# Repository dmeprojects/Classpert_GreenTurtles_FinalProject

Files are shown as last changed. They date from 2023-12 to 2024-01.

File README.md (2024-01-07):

# Classpert_GreenTurtles final project: Aim-A-Lyzer

## Links & external files
[Project report](https://docs.google.com/document/d/1ELGmE2rww3Yx6WdUTNhLceJI5xqiP-OGn81cCfm_2fU/edit#heading=h.1g53q35e8x0j)

[Device states](https://docs.google.com/spreadsheets/d/1XaL28H3fuIrutpEAfPE2s_Nis7TtN3zFUXbInfYVTSA/edit#gid=0)

[Youtube video](https://www.youtube.com/watch?v=wXm_mhuhDJE)

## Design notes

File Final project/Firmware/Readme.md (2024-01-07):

# Classpert final project: Aim-A-Lyzer

#Project report:
https://docs.google.com/document/d/1OVRfLsmoFKODwGaWP3o3U3_KX_a43jo9WVvBxGMvw9w/edit?usp=sharing

## Goal

## Hardware

### Hardware block diagram

### Software

##Libraries used;

MPU6050:
https://github.com/leech001/MPU6050

DMA info:
https://www.st.com/resource/en/application_note/an4031-using-the-stm32f2-stm32f4-and-stm32f7-series-dma-controller-stmicroelectronics.pdf

STM32 HAL user manual:
https://www.st.com/resource/en/user_manual/um1725-description-of-stm32f4-hal-and-lowlayer-drivers-stmicroelectronics.pdf

Embedded Artistery hard fault debugging:

https://embeddedartistry.com/blog/2021/01/11/hard-fault-debugging/

Asserts:

https://interrupt.memfault.com/blog/asserts-in-embedded-systems

STM viewer:

https://interrupt.memfault.com/blog/stm-viewer-debug

Unit testing:

https://interrupt.memfault.com/blog/unit-testing-basics

FatFS:
http://elm-chan.org/fsw/ff/

SD card info:
https://chlazza.nfshost.com/sdcardinfo.html

FAT FS: demo:
https://www.youtube.com/watch?v=I9KDN1o6924

SD card in SPI mode:
https://blog.domski.pl/using-fatfs-with-hal/
https://github.com/eziya/STM32_SPI_SDCARD/tree/master

STM32 SD card with SDIO:
https://www.youtube.com/watch?v=spVIZO-jbxE

#Asci art:
https://patorjk.com/software/taag/#p=testall&f=Big%20Money-sw&t=Aim-A-Lyzer

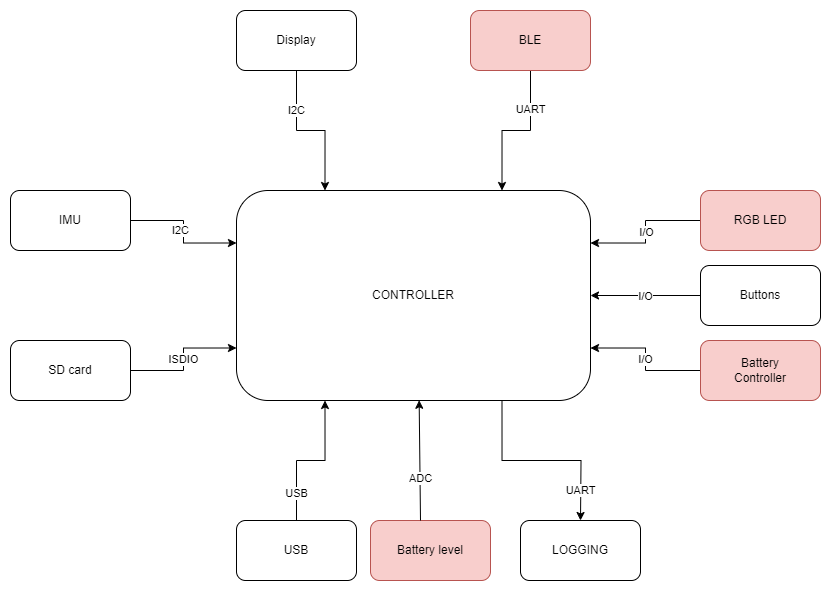
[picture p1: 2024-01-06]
docs/Hardware block diagram.png

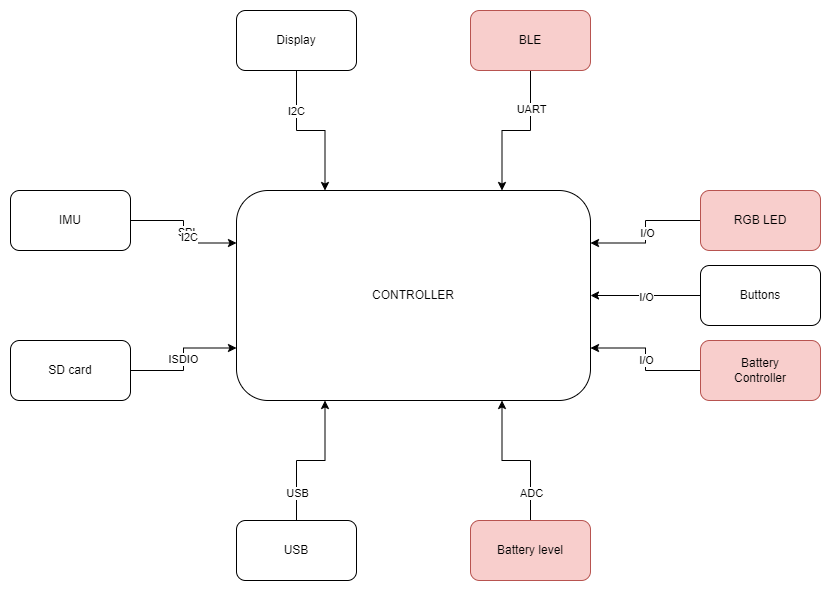
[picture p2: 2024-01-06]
docs/Hardware block diagram_MVP.png

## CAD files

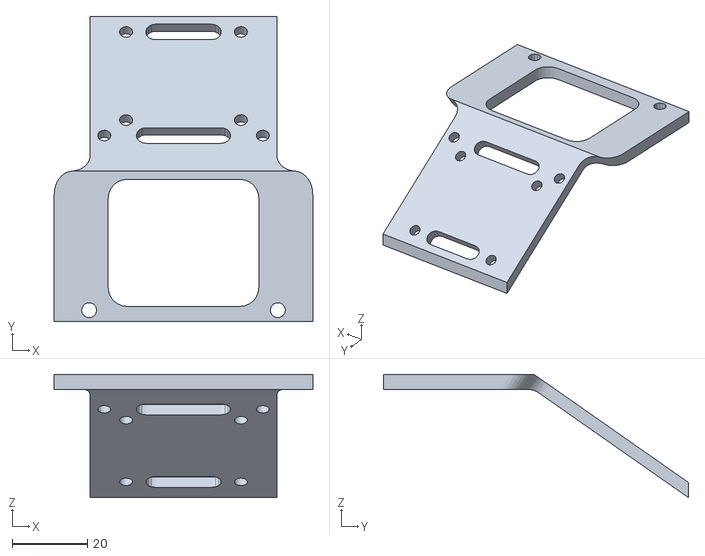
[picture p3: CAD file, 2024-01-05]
Mechanical/casing/3dPrintFiles/UserInterface mount.stl
68.5 x 80.8 x 32.7

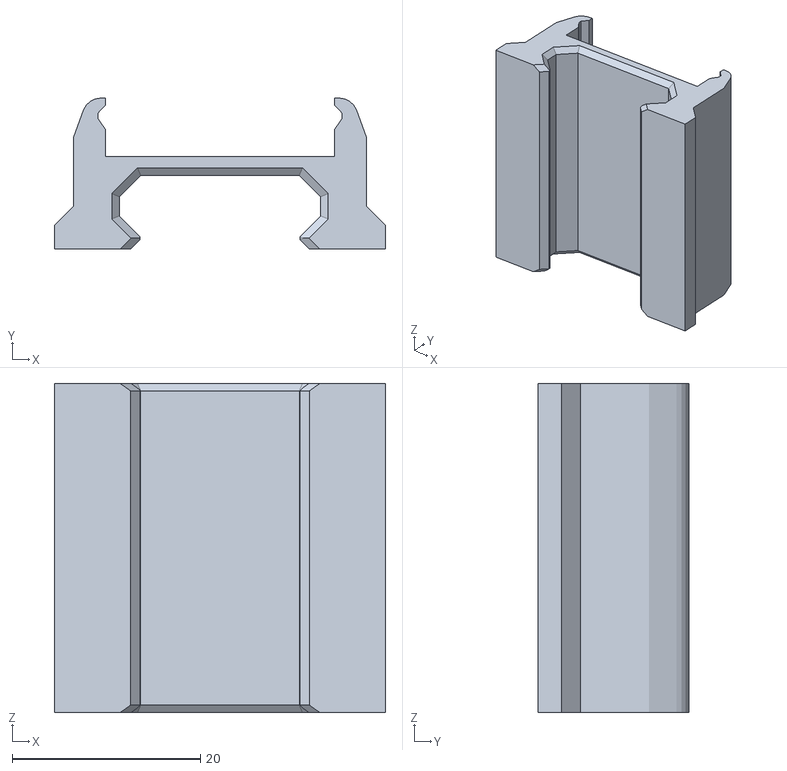
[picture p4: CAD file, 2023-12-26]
Mechanical/Rail clamp.stl
35.2 x 16.1 x 35.0

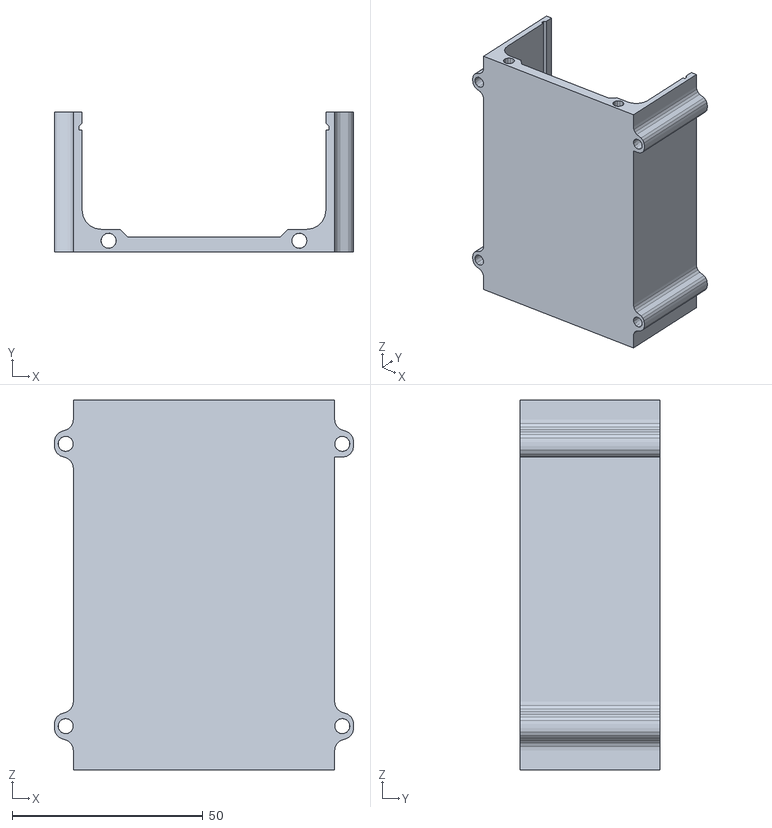
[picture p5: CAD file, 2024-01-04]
Mechanical/casing/3dPrintFiles/Discovery boar holder.stl
78.5 x 36.8 x 97.0

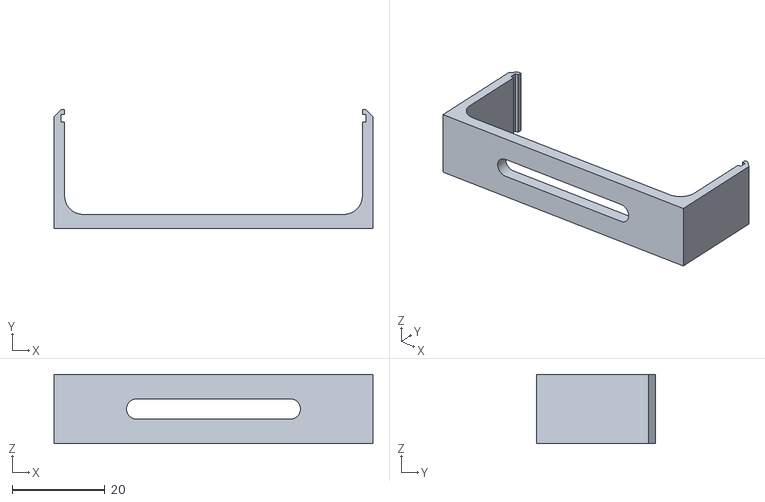
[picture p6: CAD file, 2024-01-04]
Mechanical/casing/3dPrintFiles/Discovery boar clamp.stl
68.9 x 25.6 x 15.0

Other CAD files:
Mechanical/IMU Module.ipt
Mechanical/OldVersions/IMU Module.0001.ipt
Mechanical/OldVersions/Rail assembly.0004.iam
Mechanical/OldVersions/Rail clamp.0008.ipt
Mechanical/Rail assembly.iam
Mechanical/Rail clamp.ipt
Mechanical/Rail/Picatinny model.ipt
Mechanical/casing/3dPrintFiles/OldVersions/aim-a-lyzer assy.0002.iam
Mechanical/casing/3dPrintFiles/aim-a-lyzer assy.iam
Mechanical/casing/Discovery boar clamp.ipt
Mechanical/casing/Discovery boar holder.ipt
Mechanical/casing/Discovery board.ipt
Mechanical/casing/OldVersions/Discovery boar clamp.0002.ipt
Mechanical/casing/OldVersions/Discovery boar holder.0001.ipt
Mechanical/casing/SD card holder.ipt
Mechanical/casing/UserInterface mount.ipt

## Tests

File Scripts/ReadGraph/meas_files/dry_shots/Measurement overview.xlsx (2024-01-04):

Measurement # | descirption
5 | 3x dry shots

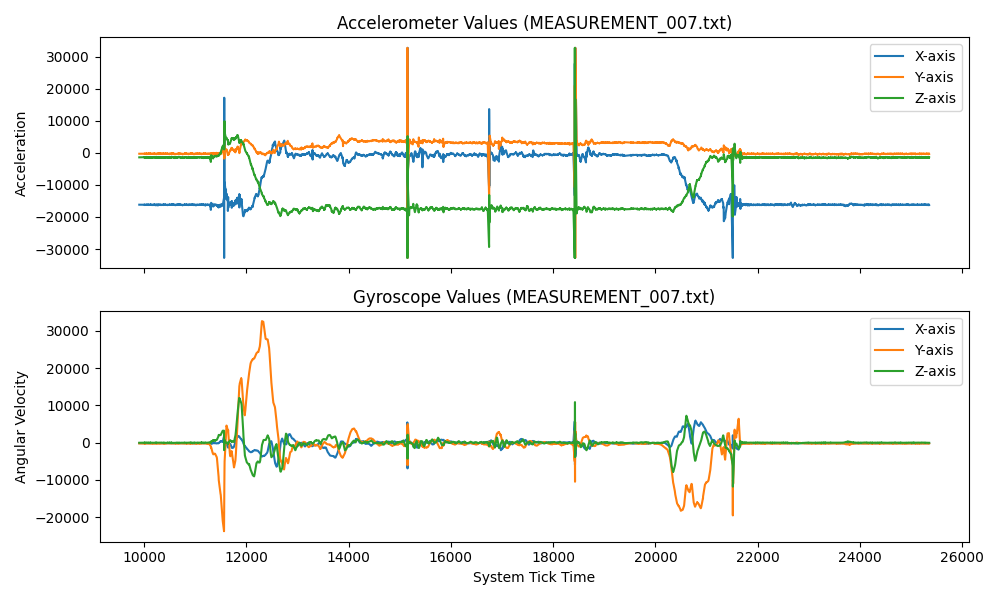
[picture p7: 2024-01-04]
Scripts/ReadGraph/meas_files/dry_shots/MEASUREMENT_007.txt.png

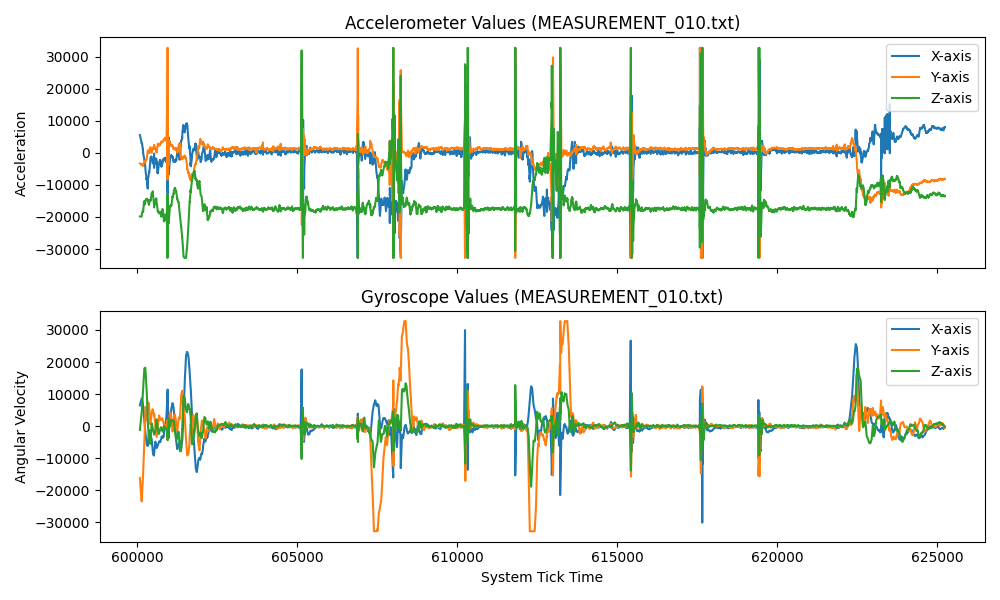
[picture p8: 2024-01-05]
Scripts/ReadGraph/meas_files/live rounds/MEASUREMENT_010.png

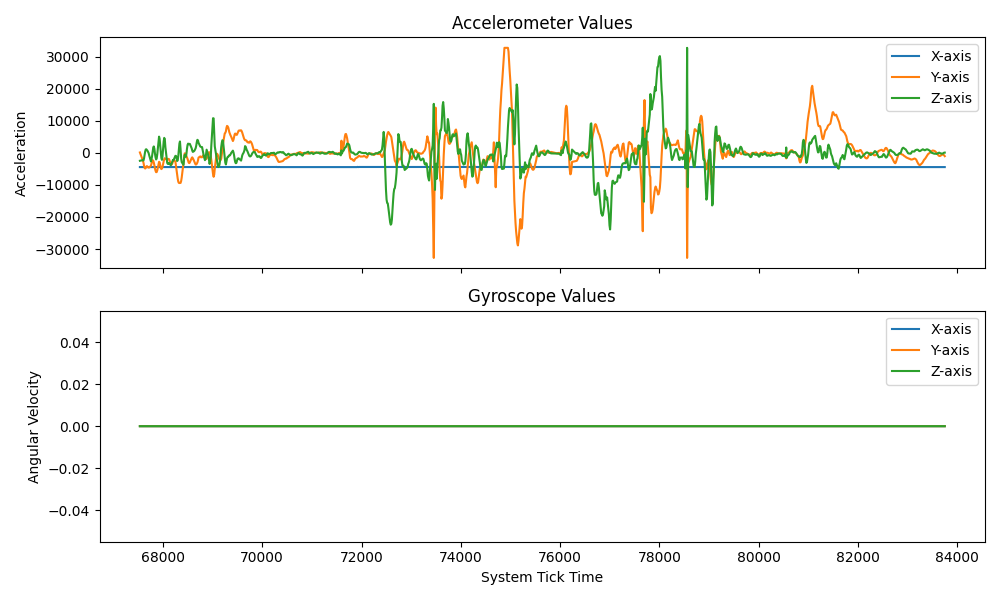
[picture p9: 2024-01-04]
Scripts/ReadGraph/meas_files/MEASUREMENT_005.png

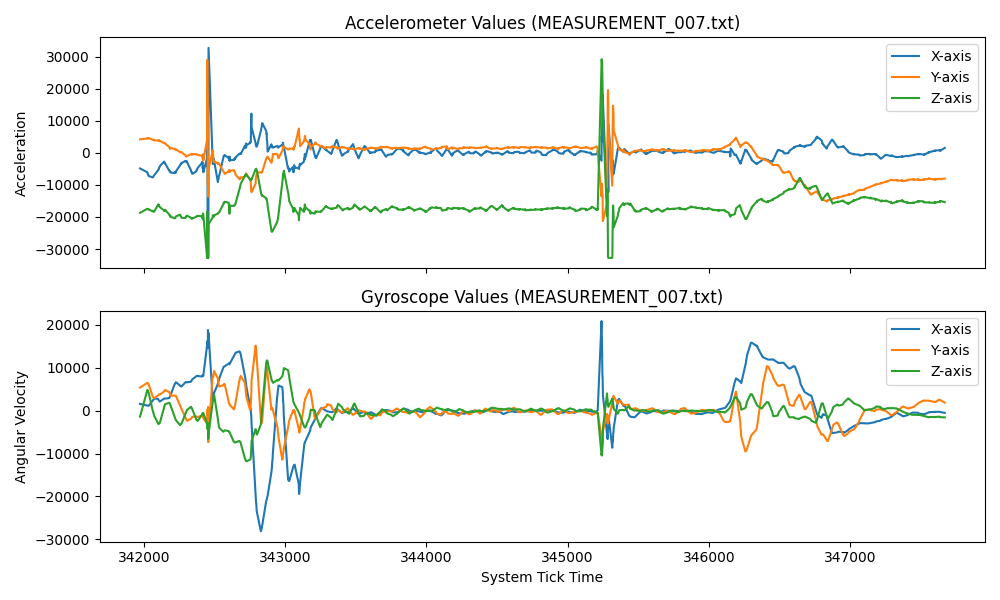
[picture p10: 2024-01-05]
Scripts/ReadGraph/meas_files/live rounds/MEASUREMENT_007.png

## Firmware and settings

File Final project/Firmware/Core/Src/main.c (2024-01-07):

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
/* Includes ------------------------------------------------------------------*/
#include "main.h"
#include "fatfs.h"
#include "usb_device.h"

/* USER CODE BEGIN Includes */
#include "custom_pindefines.h"
#include "state_defines.h"
#include "version.h"
#include "app.h"
#include "console.h"
#include "displayFunctions.h"
#include "mpu6050.h"
#include "usbd_cdc_if.h"
#include "string.h"
#include "stdarg.h"
#include "terminalColorCodes.h"
#include "logging.h"
#include "sd_handler.h"

#include "printHeader.h"
/* USER CODE END Includes */

/* USER CODE BEGIN PD */
#define ERROR_LED_DELAY	1000000
#define	ERROR_PRINT_DELAY	50
#define PUTCHAR_PROTOTYPE int __io_putchar(int ch)


#define LIBRARY_LOG_LEVEL	LOG_INFO

#define	LIBRARY_LOG_NAME	"MAIN"

/*Define if the logging output has to be send trough UART or USB.  The USB doubles as the commandline connection.
 *
 * */
#define LOGUART
//#define LOGUSB

/* USER CODE END PD */

I2C_HandleTypeDef hi2c1;
I2C_HandleTypeDef hi2c3;
DMA_HandleTypeDef hdma_i2c3_rx;

RNG_HandleTypeDef hrng;

RTC_HandleTypeDef hrtc;

SD_HandleTypeDef hsd;
DMA_HandleTypeDef hdma_sdio_rx;
DMA_HandleTypeDef hdma_sdio_tx;

SPI_HandleTypeDef hspi1;

TIM_HandleTypeDef htim2;

UART_HandleTypeDef huart2;

/* USER CODE BEGIN PV */
deviceStates_t deviceStates;
MPU6050_t mpu6050;

const char xCompileDate[] = __DATE__;
const char xCompileTime[] = __TIME__;

/* USER CODE END PV */

void SystemClock_Config(void);
static void MX_GPIO_Init(void);
static void MX_DMA_Init(void);
static void MX_I2C1_Init(void);
static void MX_TIM2_Init(void);
static void MX_RNG_Init(void);
static void MX_USART2_UART_Init(void);
static void MX_I2C3_Init(void);
static void MX_SPI1_Init(void);
static void MX_SDIO_SD_Init(void);
static void MX_RTC_Init(void);
/* USER CODE BEGIN PFP */
uint8_t sdCardpresentVar = 0;
uint32_t buttonPressed = 0;


/* USER CODE END PFP */

/**
  * @brief  The application entry point.
  * @retval int
  */
int main(void)
{
  /* USER CODE BEGIN 1 */
	unsigned char usbString[200];
  /* USER CODE END 1 */

  /* MCU Configuration--------------------------------------------------------*/

  /* Reset of all peripherals, Initializes the Flash interface and the Systick. */
  HAL_Init();

  /* Configure the system clock */
  SystemClock_Config();

  /* Initialize all configured peripherals */
  MX_GPIO_Init();
  MX_DMA_Init();
  MX_I2C1_Init();
  MX_TIM2_Init();
  MX_USB_DEVICE_Init();
  MX_RNG_Init();
  MX_USART2_UART_Init();
  MX_I2C3_Init();
  MX_FATFS_Init();
  MX_SPI1_Init();
  MX_SDIO_SD_Init();
  MX_RTC_Init();
  /* USER CODE BEGIN 2 */

  HAL_Delay(3000);	//Delay allows to reconnect USB after reboot

  printHeader();

  HAL_Delay(500);

  /*Print Firmware version*/
  logInfo( "Classpert Green Turtels Final project");
  logInfo("Aim-A-Lyzer, version: %d.%d.%d", FIRMWARE_MAJOR, FIRMWARE_MINOR, FIRMWARE_BUILD);
  logInfo("Build on: %s at %s", __DATE__, __TIME__);
  logInfo( "Created by Nick Meynen");

  startConsole();

  /* USER CODE END 2 */

  /* Infinite loop */
  /* USER CODE BEGIN WHILE */
  while (1)
  {
	  mainApp();
    /* USER CODE END WHILE */

    /* USER CODE BEGIN 3 */
  }
  /* USER CODE END 3 */
}

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
/* USER CODE BEGIN 4 */
void HAL_GPIO_EXTI_Callback(uint16_t GPIO_Pin)
{
	//HAL_GPIO_TogglePin(GPIOD, LED_ORANGE);
	//Start timer
	if(GPIO_Pin == BTN_OK || GPIO_Pin == BTN_DWN || GPIO_Pin == BTN_UP)
	{
		HAL_TIM_Base_Start_IT(&htim2);
	}
}

void HAL_TIM_PeriodElapsedCallback(TIM_HandleTypeDef *htim)
{

	if(htim->Instance == TIM2)	//Button debounce timer
	{
		htim2.Instance->SR &= ~TIM_SR_UIF;	//Clear int pending flag
		htim2.Instance->SR &= ~TIM_SR_TIF;	//Clear trigger interrupt flag
		htim2.Init.Period = 0;

		if(HAL_GPIO_ReadPin(GPIOE, BTN_OK) == 0)
		{
			HAL_GPIO_TogglePin(GPIOD, LED_ORANGE);
			buttonPressed = BTN_OK;
		}

		if(HAL_GPIO_ReadPin(GPIOE, BTN_UP) == 0)
		{
			HAL_GPIO_TogglePin(GPIOD, LED_GREEN);
			buttonPressed = BTN_UP;
		}

		if(HAL_GPIO_ReadPin(GPIOE, BTN_DWN) == 0)
		{
			HAL_GPIO_TogglePin(GPIOD, LED_BLUE);
			buttonPressed = BTN_DWN;
		}

		HAL_TIM_Base_Stop(&htim2);
		__HAL_TIM_SET_COUNTER(&htim2, 20000);
	}

}

void HAL_DMA_Callback(DMA_HandleTypeDef * hdma)
{
	//Toggle orange LED
	HAL_GPIO_TogglePin(GPIOD, LED_ORANGE);

}

void HAL_I2C_MasterRxCptlCallback(I2C_HandleTypeDef * hi2c)
{
	HAL_GPIO_TogglePin(GPIOD, LED_GREEN);
}

void HAL_I2C_MemRxCpltCallback(I2C_HandleTypeDef *hi2c)
{
	HAL_GPIO_TogglePin(GPIOD, LED_BLUE);
}

PUTCHAR_PROTOTYPE
{
#ifdef LOGUART
	HAL_UART_Transmit(&huart2, (uint8_t *)&ch, 1, 0xFFFF);
	return 0;
#endif

#ifdef LOGUSB
	CDC_Transmit_FS((uint8_t *)&ch, 1);
	return 0;
#endif
}

/* USER CODE END 4 */
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


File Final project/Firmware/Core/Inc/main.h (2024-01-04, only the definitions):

#define CS_I2C_SPI_Pin GPIO_PIN_3
#define CS_I2C_SPI_GPIO_Port GPIOE
#define PC14_OSC32_IN_Pin GPIO_PIN_14
#define PC14_OSC32_IN_GPIO_Port GPIOC
#define PC15_OSC32_OUT_Pin GPIO_PIN_15
#define PC15_OSC32_OUT_GPIO_Port GPIOC
#define PH0_OSC_IN_Pin GPIO_PIN_0
#define PH0_OSC_IN_GPIO_Port GPIOH
#define PH1_OSC_OUT_Pin GPIO_PIN_1
#define PH1_OSC_OUT_GPIO_Port GPIOH
#define OTG_FS_PowerSwitchOn_Pin GPIO_PIN_0
#define OTG_FS_PowerSwitchOn_GPIO_Port GPIOC
#define B1_Pin GPIO_PIN_0
#define B1_GPIO_Port GPIOA
#define B1_EXTI_IRQn EXTI0_IRQn
#define BOOT1_Pin GPIO_PIN_2
#define BOOT1_GPIO_Port GPIOB
#define BTN_UP_Pin GPIO_PIN_11
#define BTN_UP_GPIO_Port GPIOE
#define BTN_UP_EXTI_IRQn EXTI15_10_IRQn
#define BTN_OK_Pin GPIO_PIN_13
#define BTN_OK_GPIO_Port GPIOE
#define BTN_OK_EXTI_IRQn EXTI15_10_IRQn
#define BTN_DWN_Pin GPIO_PIN_15
#define BTN_DWN_GPIO_Port GPIOE
#define BTN_DWN_EXTI_IRQn EXTI15_10_IRQn
#define LD4_Pin GPIO_PIN_12
#define LD4_GPIO_Port GPIOD
#define LD3_Pin GPIO_PIN_13
#define LD3_GPIO_Port GPIOD
#define LD5_Pin GPIO_PIN_14
#define LD5_GPIO_Port GPIOD
#define LD6_Pin GPIO_PIN_15
#define LD6_GPIO_Port GPIOD
#define IMU_INT_Pin GPIO_PIN_6
#define IMU_INT_GPIO_Port GPIOC
#define SD_DET_Pin GPIO_PIN_7
#define SD_DET_GPIO_Port GPIOC
#define VBUS_FS_Pin GPIO_PIN_9
#define VBUS_FS_GPIO_Port GPIOA
#define OTG_FS_DM_Pin GPIO_PIN_11
#define OTG_FS_DM_GPIO_Port GPIOA
#define OTG_FS_DP_Pin GPIO_PIN_12
#define OTG_FS_DP_GPIO_Port GPIOA
#define SWDIO_Pin GPIO_PIN_13
#define SWDIO_GPIO_Port GPIOA
#define SWCLK_Pin GPIO_PIN_14
#define SWCLK_GPIO_Port GPIOA
#define Audio_RST_Pin GPIO_PIN_4
#define Audio_RST_GPIO_Port GPIOD
#define OTG_FS_OverCurrent_Pin GPIO_PIN_5
#define OTG_FS_OverCurrent_GPIO_Port GPIOD
#define Audio_SCL_Pin GPIO_PIN_6
#define Audio_SCL_GPIO_Port GPIOB
#define Audio_SDA_Pin GPIO_PIN_9
#define Audio_SDA_GPIO_Port GPIOB
#define MEMS_INT2_Pin GPIO_PIN_1
#define MEMS_INT2_GPIO_Port GPIOE

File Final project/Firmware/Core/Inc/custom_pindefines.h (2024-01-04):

/*
 * custom_pindefines.h
 *
 *  Created on: Oct 15, 2023
 *      Author: nick_
 */

#ifndef INC_CUSTOM_PINDEFINES_H_
#define INC_CUSTOM_PINDEFINES_H_

#define LED_GREEN	LD4_Pin
#define	LED_RED		LD5_Pin
#define	LED_ORANGE	LD3_Pin
#define	LED_BLUE	LD6_Pin

#define BUTTON1		B1_Pin
#define BTN_UP		BTN_UP_Pin
#define	BTN_DWN		BTN_DWN_Pin
#define BTN_OK		BTN_OK_Pin



#endif /* INC_CUSTOM_PINDEFINES_H_ */

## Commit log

2023-10-12 created cube MX project for STM eval board
2023-10-12 Added timer2 as general purpose timer
2023-10-15 Remnoved old project due to toolchain config issues and created a new one.
    [main.c, main.h]
2023-10-15 Added blinking LEDS with 100ms delay between
2023-10-20 Started mechanical drafting + added interrupts to week 3 assignment
    [IMU Module.ipt, Picatinny model.ipt, Rail assembly.iam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]
2023-10-26 Added CAD files
    [Rail assembly.0001.iam, Rail assembly.iam, Rail clamp.0002.ipt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]
2023-10-26 Fixed code and working CDC
    [app.c]
2023-10-30 Removed driver, middleware, and usb host from gitignore file
2023-11-01 Code runs with USB active, but still crashes when receiving a character
    [app.c, consoleIO.c, main.c]
2023-11-05 fixed console for USB CDC
    [app.c, consoleIO.c]
2023-11-05 Added LED pattern to commands
2023-11-05 Added imu registers
2023-11-06 SPI implemented, but has still the wrong data on the logic analyzer
    [main.c]
2023-11-08 Fixed SPI communication. Added reset of the IMU before the read out of who am i reg
2023-11-08 Fixed spi issue. Installed accellerometer is the LIS3DSH. Inserted the STM32 libraries
    [main.c]
2023-11-16 Added diagrams to the final project folder and adjusted the IMU PCB heigth in the mechanical design
    [Rail assembly.0001.iam, Rail assembly.0002.iam, Rail assembly.iam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]
2023-11-16 Added SSD1306 for STM32 submodule
2023-11-16 Increased the heigth of the IMU on the rail clamp
    [Rail clamp.0004.ipt, Rail clamp.0005.ipt, Rail clamp.ipt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]
2023-11-19 qdded ssd1306 driver
2023-11-23 Removed vertical size test. Added raw IMU readouts to put on screen
2023-11-25 Added MPU9250 IMU unit, but this seems a counterfeit part. Changed to MPU6050 in I2C mode
2023-11-30 Added gyro values to display
2023-11-30 commented out the led pattern and display update code to speed up IMU sampling rate
2023-12-14 Added json file to keep track of the version numbers
2023-12-18 Added kalman values to printout
2023-12-18 Added DMA test
2023-12-21 Added DMA: Issue with MPU6050, the device needs sometimes a power reset when starting for the first time
    [Classpert_Final_Project.ioc, main.c, mpu6050.c]
2023-12-21 Fixed DMA
2023-12-22 Added dma to imu driver
2023-12-26 Added mechanical folder with rail clamp design
    [IMU Module.0001.ipt, IMU Module.ipt, Picatinny model.ipt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]
2023-12-26 Added console command to read IMU data
2023-12-27 Changed sd card driver to spi mode
2023-12-28 SD card testing...
    [Rail assembly.0003.iam, Rail assembly.0004.iam, Rail assembly.iam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]
2023-12-29 Switched back to sdio, and followed the tutorial on https://www.youtube.com/watch?v=I9KDN1o6924 => enable DMA and interrupt. Now getting the FR_OK after the f_mkfs file
2023-12-30 Changed SD card detect gpio pin to fit on same header as sdio pins
2024-01-02 Added print and led blink to error_handler
    [app.c, main.c]
2024-01-02 Added timer to button interrupt
2024-01-04 Changed tim2 to count down to easy retrigger for a button press
2024-01-04 Implemented imu measurements to file
2024-01-04 Added some measurements
    [Measurement overview.xlsx]
2024-01-04 Added base holder for case holder
    [Discovery boar clamp.0002.ipt, Discovery boar clamp.ipt, Discovery boar clamp.stl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]
2024-01-04 Added 3 buttons, and tested with measurement 007: 3 dry shots
2024-01-04 Added functions in SDcard library to return file name and samples taken
2024-01-05 Added user interface holder in mechanical designs.
    [UserInterface mount.stl, aim-a-lyzer assy.0001.iam, aim-a-lyzer assy.iam]
2024-01-05 Added live fire measurements3
    [Measurement overview.xlsx]
2024-01-06 Added user interface mount
    [UserInterface mount.ipt, aim-a-lyzer assy.0001.iam, aim-a-lyzer assy.0002.iam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]
2024-01-07 CLeanup old files
    [IMU Module.ipt, Picatinny model.ipt, Rail assembly.0002.iam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]

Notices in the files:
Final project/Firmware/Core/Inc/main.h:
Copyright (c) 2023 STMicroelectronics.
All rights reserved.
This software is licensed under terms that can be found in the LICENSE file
